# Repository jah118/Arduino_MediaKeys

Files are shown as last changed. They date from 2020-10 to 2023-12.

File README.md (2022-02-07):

# Arduino_MediaKeys

This project is to make custom key for windows, as of now it is used for media keys (prev,next,play/pause) and to use F19 and F16 to keybinds for discord or what key is defined

the future for project, is to add a display that can pull information from spotify and display the song and more info as a start.

# Dependencies:

HID-Project by NicoHood Version 2.5.0 or above

- can be found in Arduino Lirary Manager
- or: https://github.com/NicoHood/HID

BOUNCE 2 Debouncing library for Arduino and Wiring by Thomas Ouellet Fredericks
- can be found in Arduino Lirary Manager
- or:  https://github.com/thomasfredericks/Bounce2

# Reference:

The Reference links below is where the info to getting the project to work comes from

- https://uboopenfactory.univ-brest.fr/Les-Labs/MusicLab/Projets/Arduino-Media-Keys

## Most code inspiration comes from here:

- https://github.com/NicoHood/HID/wiki
- https://www.arduino.cc/reference/en/language/functions/usb/keyboard/
- https://www.stefanjones.ca/blog/arduino-leonardo-remote-multimedia-keys/
- https://arduino.stackexchange.com/questions/8934/send-keyboard-media-keys-with-keyboard-library
- http://www.freebsddiary.org/APC/usb_hid_usages.php
- list of hid codes for further use or differt use case
  https://www.instructables.com/id/USB-Volume-Control-and-Caps-Lock-LED-Simple-Cheap-/

# PCB

`the pcb was design in eagle`  
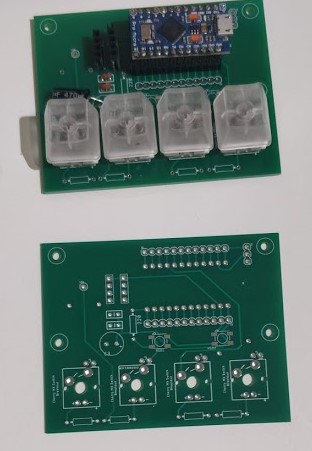
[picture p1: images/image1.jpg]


### With old prototype board

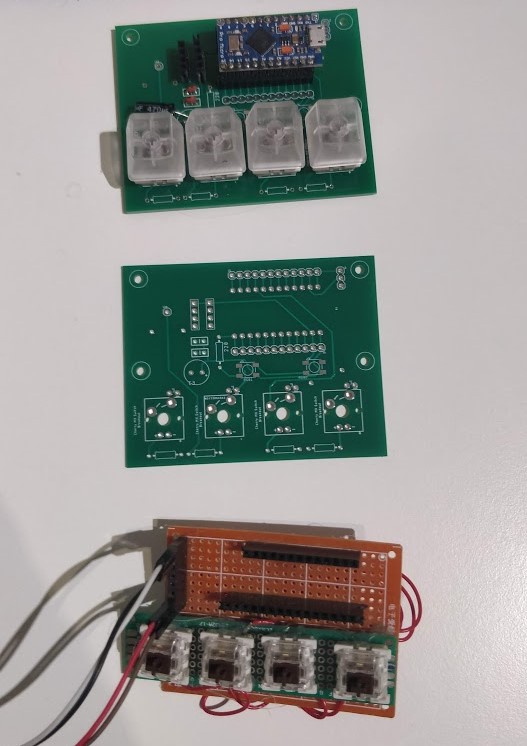
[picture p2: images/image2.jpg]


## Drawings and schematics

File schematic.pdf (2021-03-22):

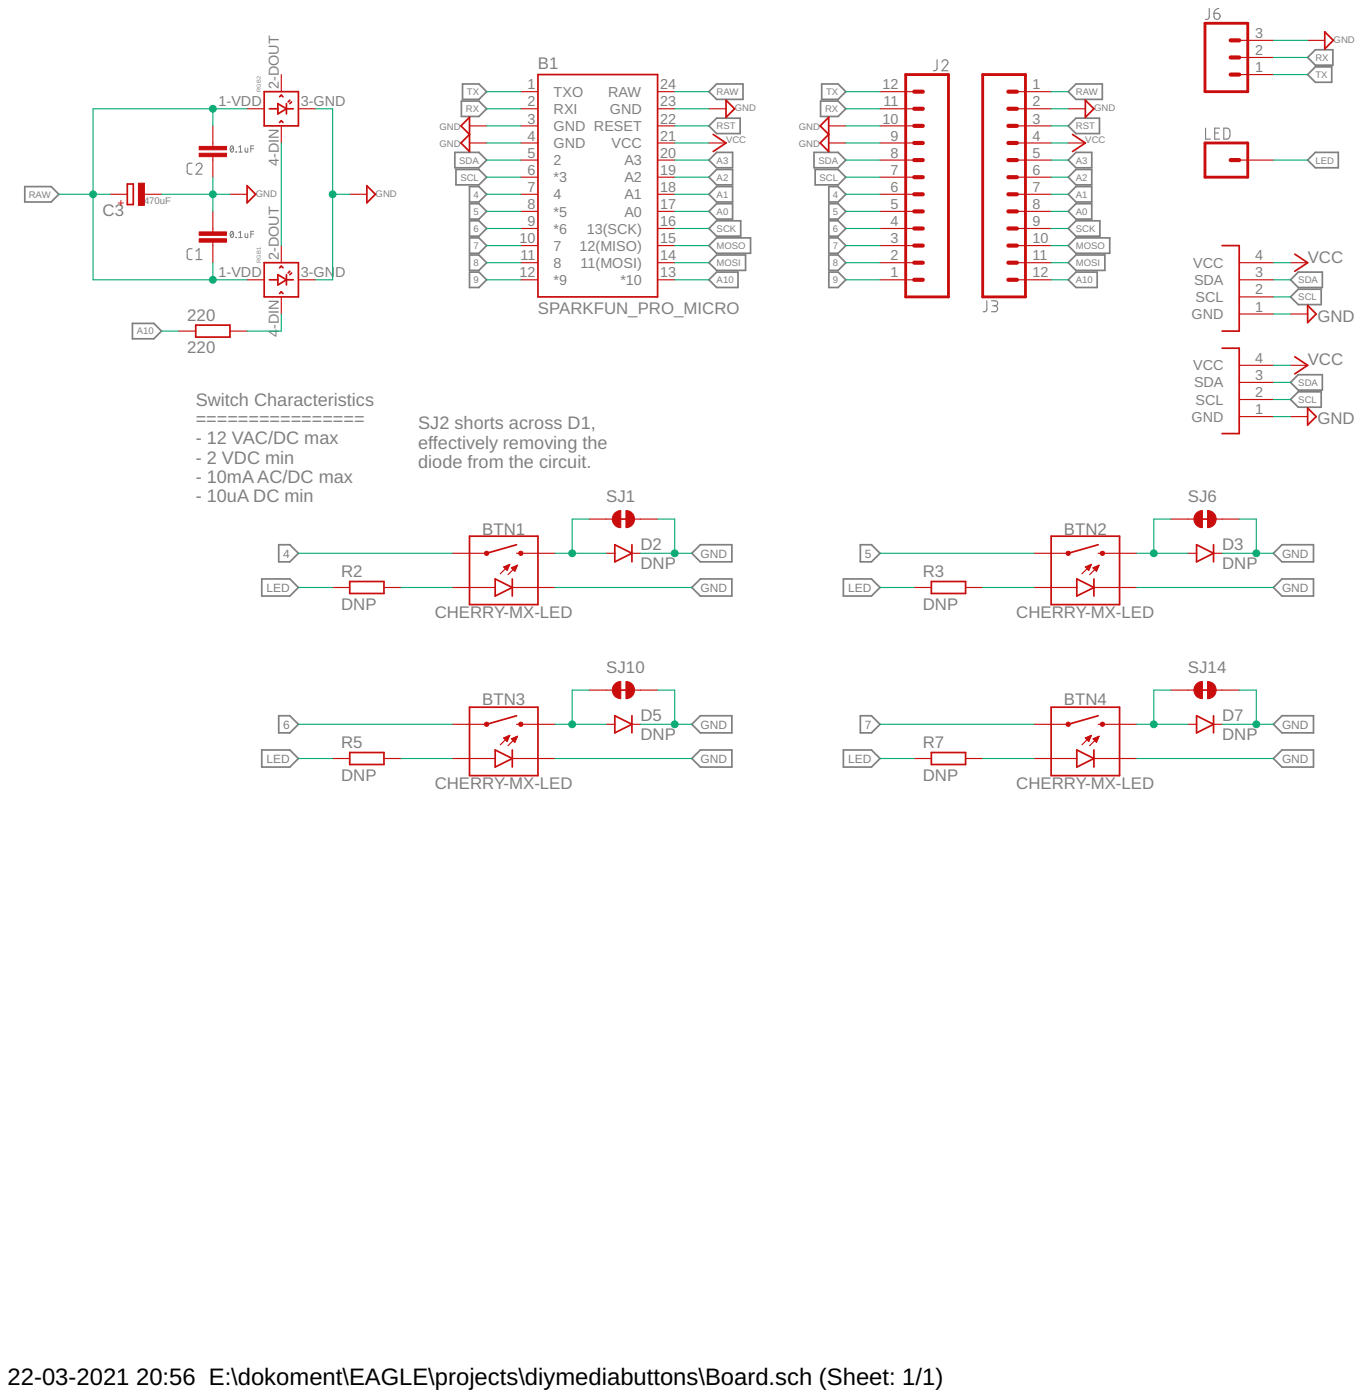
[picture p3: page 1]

diode from the circuit. Switch Characteristics ================

SJ2 shorts across D1, effectively removing the

22-03-2021 20:56 E:\dokoment\EAGLE\projects\diymediabuttons\Board.sch (Sheet: 1/1)

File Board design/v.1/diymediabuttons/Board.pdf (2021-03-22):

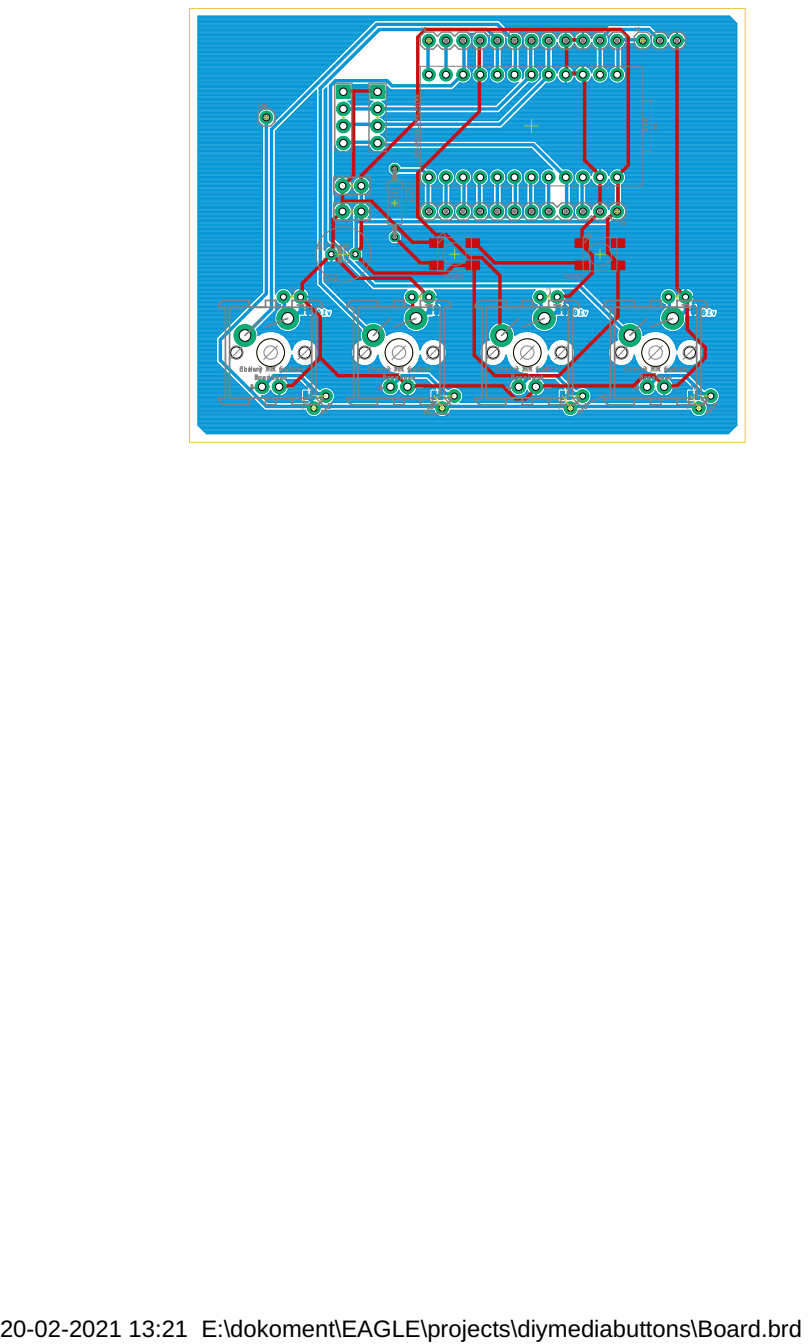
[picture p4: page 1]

20-02-2021 13:21 E:\dokoment\EAGLE\projects\diymediabuttons\Board.brd

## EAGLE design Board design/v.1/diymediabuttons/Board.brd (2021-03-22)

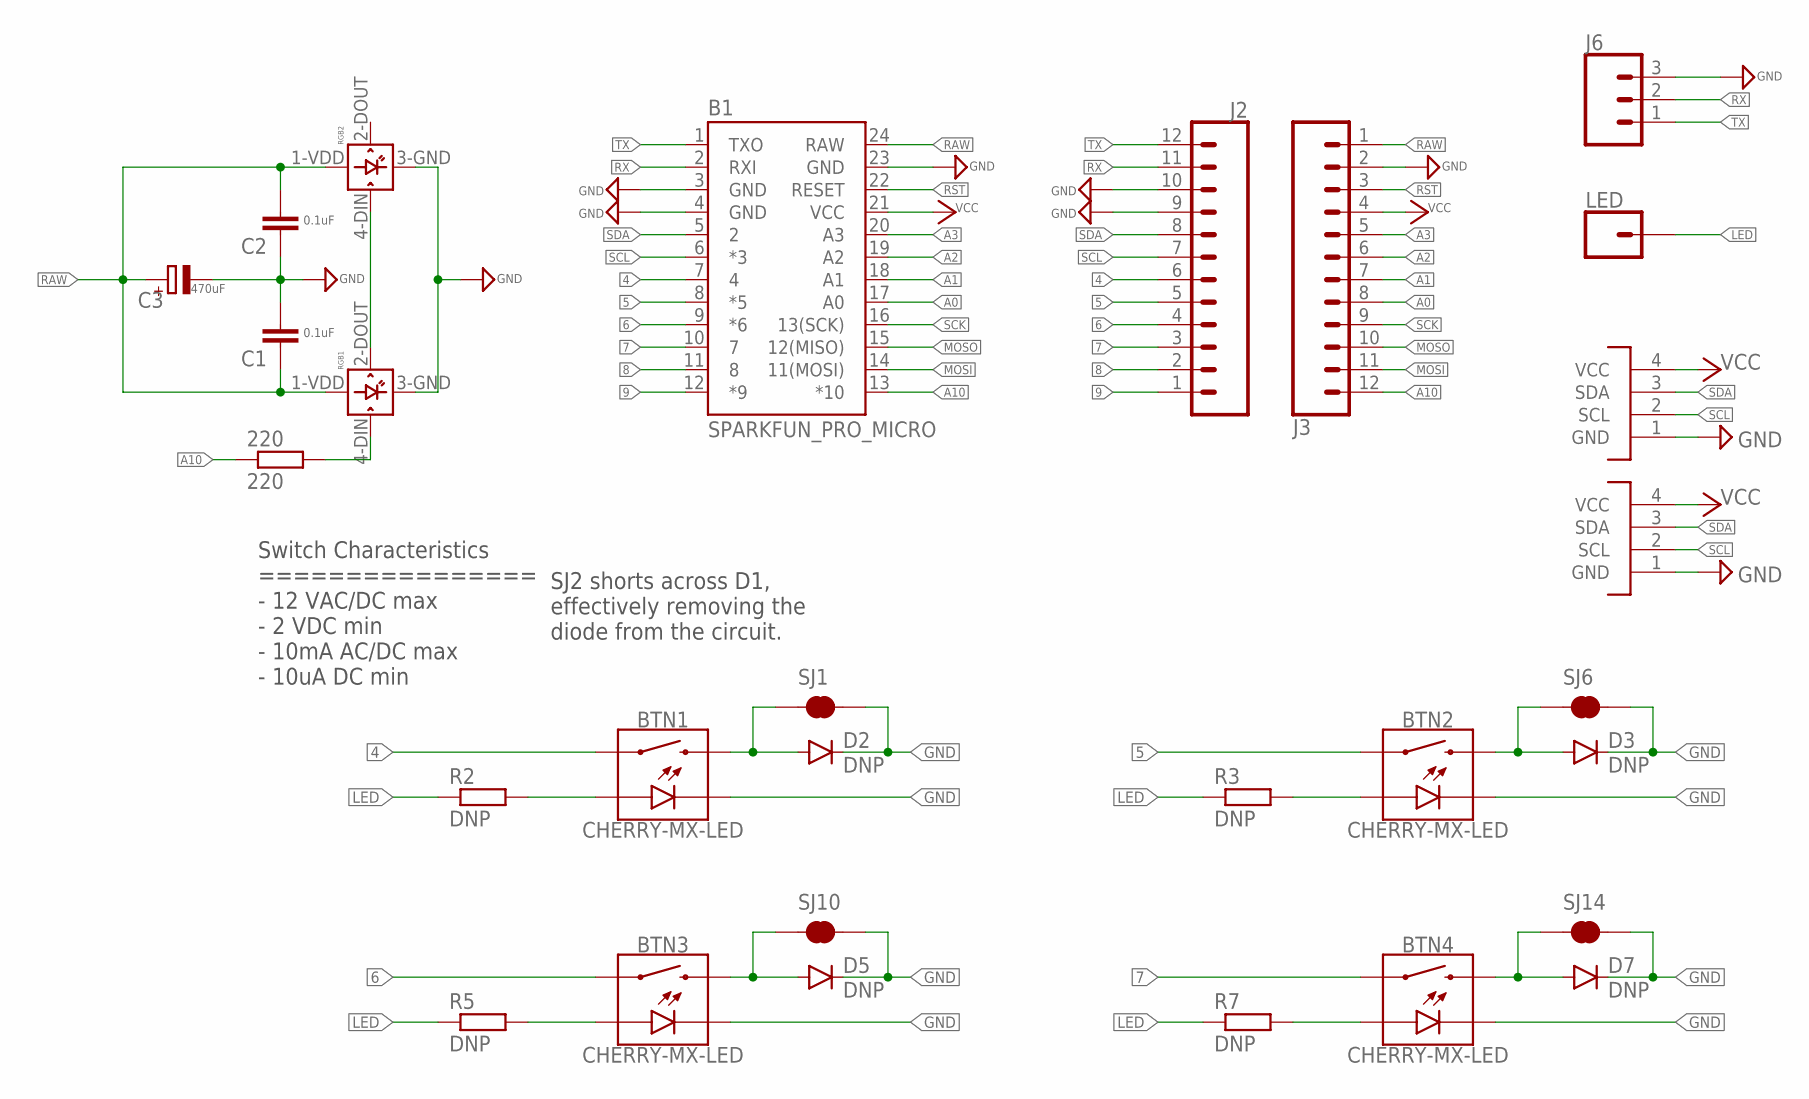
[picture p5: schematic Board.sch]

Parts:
220: 220; 0207/10
B1: SPARKFUN_PRO_MICRO
BTN1, BTN2, BTN3, BTN4: CHERRY-MX-LED
C1, C2: 0.1uF; CAP-PTH-SMALL-KIT
C3: 470uF; E3,5-8
D2, D3, D5, D7: DNP; DIODE-PTH-0.1
J2, J3: CONN_12; 1X12
J4, J5: I2C-HEADER; HEADER-4X1-2.54
J6: CONN_03; 1X03
LED: CONN_01; 1X01
R2, R3, R5, R7: DNP; 0207/10
RGB1, RGB2: WS2812B
SJ1, SJ6, SJ10, SJ14: JUMPER-PAD-2-NC_BY_TRACENO_SILK; PAD-JUMPER-2-NC_BY_TRACE_NO_SILK

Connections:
4: B1.7 (4), BTN1.S1, J2.6
5: B1.8 (*5), BTN2.S1, J2.5
6: B1.9 (*6), BTN3.S1, J2.4
7: B1.10 (7), BTN4.S1, J2.3
8: B1.11 (8), J2.2
9: B1.12 (*9), J2.1
A0: B1.17 (A0), J3.8
A1: B1.18 (A1), J3.7
A2: B1.19 (A2), J3.6
A3: B1.20 (A3), J3.5
A10: 220.1, B1.13 (*10), J3.12
GND: B1.3 (GND), B1.4 (GND), B1.23 (GND), BTN1.K (C), BTN2.K (C), BTN3.K (C), BTN4.K (C), C1.2, C2.1, C3.-, D2.C, D3.C, D5.C, D7.C, J2.9, J2.10, J3.2, J4.1 (GND), J5.1 (GND), J6.3, RGB1.3-GND (GND), RGB2.3-GND (GND), SJ1.2, SJ6.2, SJ10.2, SJ14.2
LED: LED.1, R2.1, R3.1, R5.1, R7.1
MOSI: B1.14 (11(MOSI)), J3.11
MOSO: B1.15 (12(MISO)), J3.10
unnamed: BTN1.A, R2.2
unnamed: 220.2, RGB1.4-DIN (DIN)
unnamed: RGB1.2-DOUT (DOUT), RGB2.4-DIN (DIN)
unnamed: BTN1.S2, D2.A, SJ1.1
unnamed: BTN2.A, R3.2
unnamed: BTN2.S2, D3.A, SJ6.1
unnamed: BTN3.A, R5.2
unnamed: BTN3.S2, D5.A, SJ10.1
unnamed: BTN4.A, R7.2
unnamed: BTN4.S2, D7.A, SJ14.1
RAW: B1.24 (RAW), C1.1, C2.2, C3.+, J3.1, RGB1.1-VDD (VDD), RGB2.1-VDD (VDD)
RST: B1.22 (RESET), J3.3
RX: B1.2 (RXI), J2.11, J6.2
SCK: B1.16 (13(SCK)), J3.9
SCL: B1.6 (*3), J2.7, J4.2 (SCL), J5.2 (SCL)
SDA: B1.5 (2), J2.8, J4.3 (SDA), J5.3 (SDA)
TX: B1.1 (TXO), J2.12, J6.1
VCC: B1.21 (VCC), J3.4, J4.4 (VCC), J5.4 (VCC)

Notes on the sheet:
SJ2 shorts across D1, effectively removing the diode from the circuit.
Switch Characteristics ================ - 12 VAC/DC max - 2 VDC min - 10mA AC/DC max - 10uA DC min

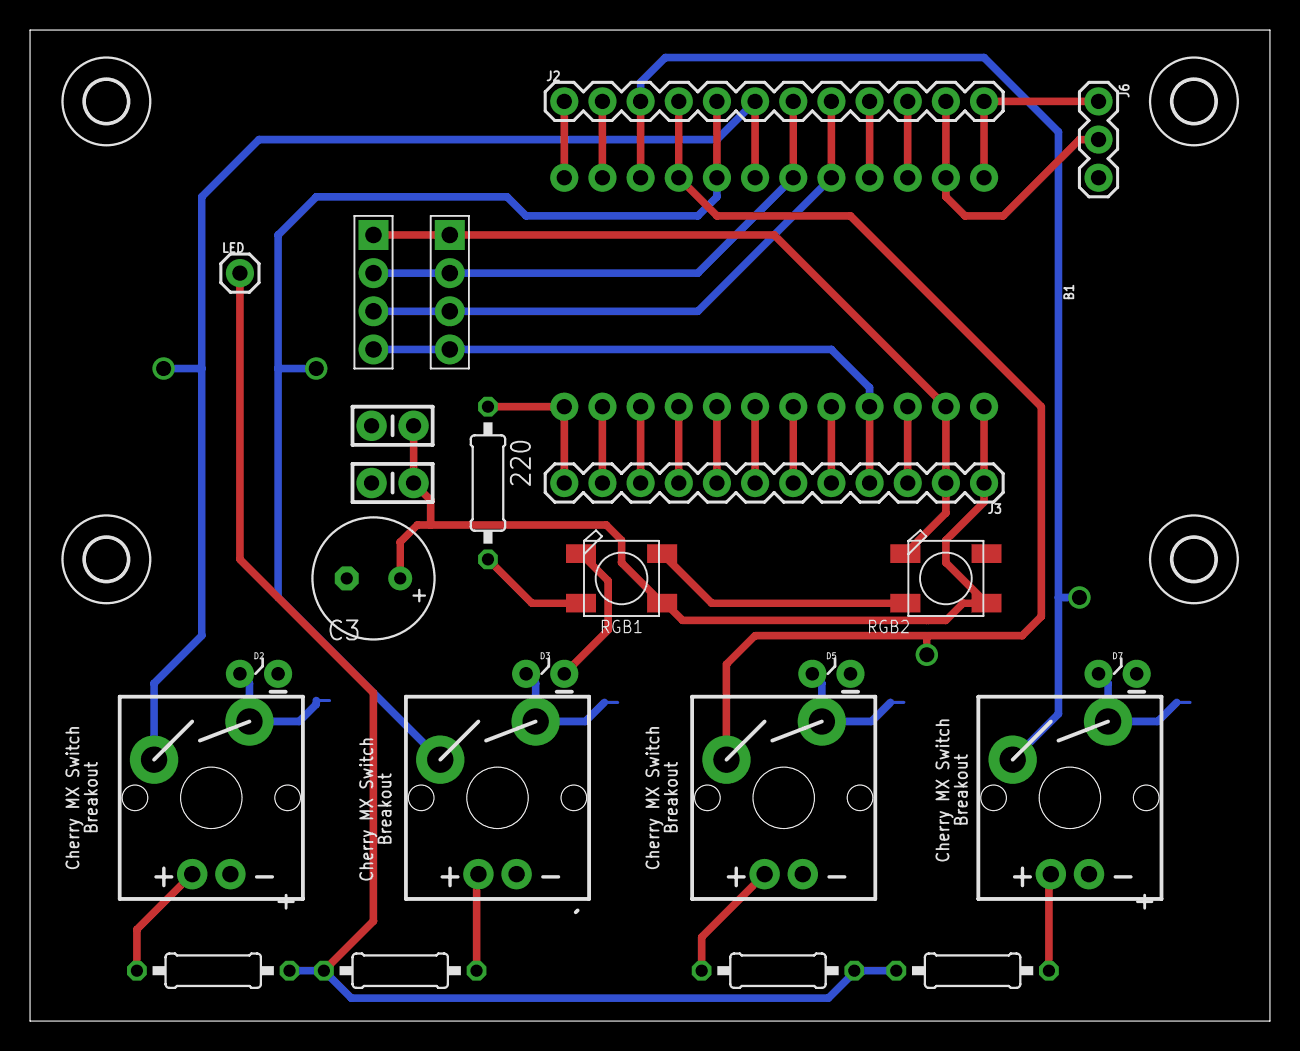
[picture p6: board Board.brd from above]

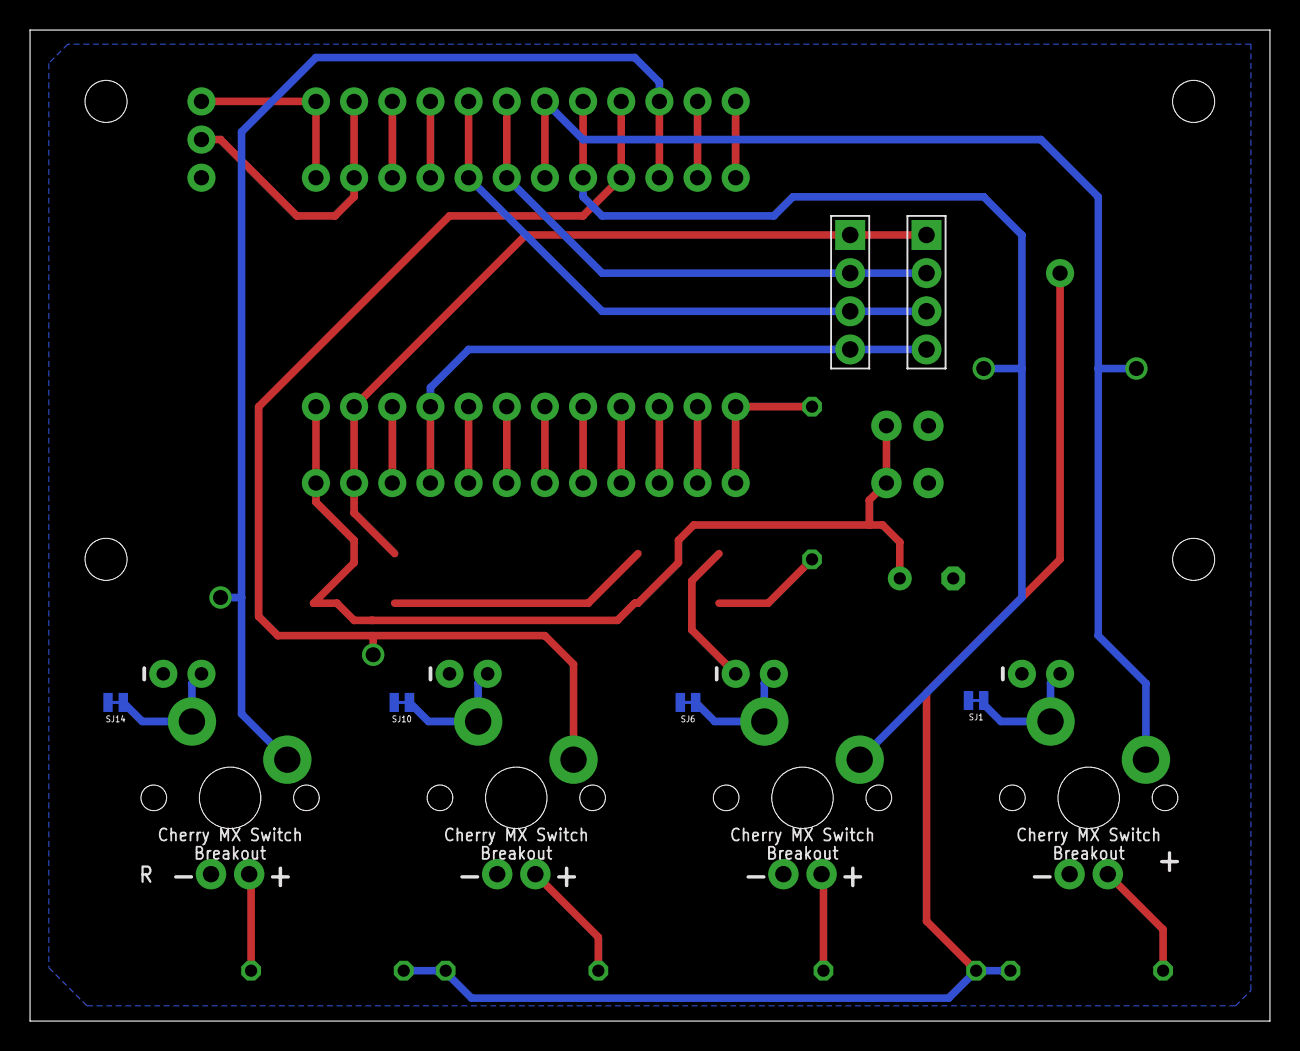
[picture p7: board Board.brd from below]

Board: 2 copper layers, 82.5 x 66.0 mm, 33 parts (4 on the bottom side), 33 nets.

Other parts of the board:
U$1, U$2, U$3, U$4: 2,8

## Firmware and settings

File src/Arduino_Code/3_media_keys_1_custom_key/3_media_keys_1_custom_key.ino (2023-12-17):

/*
  Jonas

  Arduino Media Keys
  Version V0.8.1
  10/12/2023

  Dependencies:
  - HID-Project by NicoHood Version 2.8.4 or above
    -- can be found in Arduino Lirary Manager
    -- or: https://github.com/NicoHood/HID
  
  - FastLED
  - Bounce2

  Reference:
  The Reference links below is where the info to getting the project to work comes from
   @see https://uboopenfactory.univ-brest.fr/Les-Labs/MusicLab/Projets/Arduino-Media-Keys
  - most code comes from here.
  @see https://github.com/NicoHood/HID/wiki
  @see https://www.arduino.cc/reference/en/language/functions/usb/keyboard/
  @see https://www.stefanjones.ca/blog/arduino-leonardo-remote-multimedia-keys/
  @see https://arduino.stackexchange.com/questions/8934/send-keyboard-media-keys-with-keyboard-library
  @see http://www.freebsddiary.org/APC/usb_hid_usages.php
  - list of hid codes for further use or differt use case
  @see https://www.instructables.com/id/USB-Volume-Control-and-Caps-Lock-LED-Simple-Cheap-/
  @see https://docs.arduino.cc/hacking/software/LibraryTutorial

  double press solutin based on:
  MULTI-CLICK:  One Button, Multiple Events Based on "https://jmsarduino.blogspot.com/2009/10/4-way-button-click-double-click-hold.html"

*/


/*
  ///       V0.8 - done
      use #include <Bounce2.h> for better double  press
      https://arduino.stackexchange.com/questions/69897/detecting-how-many-button-pressessingle-tap-double-tap-etc-with-two-simultane

      ensure / add support for auto change beween linux and windows.
  
  ///       V0.8.1 - done
      * Replaced Bounce2.h as  double  press handler using :
        MULTI-CLICK:  One Button, Multiple Events Based on "https://jmsarduino.blogspot.com/2009/10/4-way-button-click-double-click-hold.html"

      *  Moved  Button code to lib : Button.h
      * started on V0.9.0 base classes for loading confs

  ///       TODO FOR V0.9.0
      change over to load key map file - maybejson
      read json AND  read it from pc program or some nice wayy that needs no reflash :
      https://forum.arduino.cc/t/writing-to-flash-from-application-please-test-and-enjoy/320295
      https://arduinoplusplus.wordpress.com/2019/04/02/persisting-application-parameters-in-eeprom/
      https://arduinojson.org/v6/how-to/store-a-json-document-in-eeprom/
      https://arduinojson.org/
      https://arduinojson.org/v6/how-to/reduce-memory-usage/

  ///        TODO goals for v1.0.0
        add serial support between arduione and esp to send keypress or recives keypress
      - reason this is to add support for esp or raspberry zero with screen that shows media status.
      - if zero is used then a webpage can be used. show and pull data from there. do browser in terminal to save resources, and make it host is own webpages that is displayed
      - if esp is used thne look in to building ui that where some part is static and and only progress bar moves https://forum.arduino.cc/t/tft-touch-reaching-high-refresh-rate-cost-effectively/595823/6
        and rest of sreen updates only on new song changed (this not for first version, first version shows the name of the song played  )
        https://www.youtube.com/watch?v=rq5yPJbX_uk
        https://www.esp8266.com/viewtopic.php?f=32&t=16366


*/


/// look up hid projekt to see Languages  or see AlternateLanguageLayout.ino from hid project for example
#define HID_CUSTOM_LAYOUT  // set this flag to indicate that a custom layout is selected
#define LAYOUT_DANISH      // set this flag after the above flag to indicate the custom input method is DANISH

/// include the HID library
#include "HID-Project.h"
#include "FastLED.h"
#include "Bounce2.h"

/// @todo add defin things to struct and load from json



//------------------------------ rgb ------------------------------
#define DATA_PIN 9
//#define CLK_PIN 4
#define LED_TYPE WS2811
#define COLOR_ORDER GRB
#define NUM_LEDS 8
#define BRIGHTNESS 32

/// @todo maybe move beacause of loading order of data and info from config
CRGB leds[NUM_LEDS];

int rgbState = 1;
int lastrgbState = 0;

/// ------------------------------ Buttons press vars ------------------------------
/// press var's for determening a press or double press
const int holdTime = 1000;
const unsigned long lastSwitchTime = 0;
const long DCgap = 250;   // 150 //230   // time for captureing a double press
const int debounce = 20;  // 50 //20 // 35
const byte BUTTON_DEBOUNCE_INTERVAL = 25;

const byte buttonPin1 = 4;  // key 1 backButton
const byte buttonPin2 = 5;  // key 2 playButton
const byte buttonPin3 = 6;  // key 3 fwdButton
const byte buttonPin4 = 7;  // key 4 customButton F16/F19

const uint8_t buttonPin1Action = MEDIA_PREVIOUS;
const uint8_t buttonPin2Action = MEDIA_PLAY_PAUSE;
const uint8_t buttonPin3Action = MEDIA_NEXT;
const uint8_t buttonPin4Action1 = KEY_F19;
const uint8_t buttonPin4Action2 = KEY_F16;

/// ------------------------------ DEBUG ------------------------------
/// Determs if Serial.print is enabled
const bool debugState = false;

void isDebugTruePrintToSerial(String temp) {
  if (debugState) {
    Serial.println(temp);
  }
}

/// ------------------------------ Dataconf ------------------------------
/// Struct to hold the general config like colours.
struct Config {
  char layout;
  uint16_t datapin;
  char ledtype;
  char colororder;
  uint16_t nleds;
  uint16_t brightness;
  uint8_t debounce;  // ms debounce period to prevent flickering when pressing or releasing the button
  uint8_t holdTime;  // ms hold period: how long to wait for press+hold event
  uint8_t DCgap;     // max ms between clicks for a double click event
  uint8_t attempts;
  uint16_t attemptdelay;
};

///--------- Internal references ------------
/// (this needs to be below all structs etc..) this may needed to be loaded after struct
/// #include "configLoad.h"
#include "Button.h"

/// -------------- Start Button  ----------------------
/// Bounce2.h lib setup
Bounce button1Debouncer = Bounce();
Bounce button2Debouncer = Bounce();
Bounce button3Debouncer = Bounce();

/// Button.h lib setup
Button Button1(buttonPin1, debugState);
Button Button2(buttonPin2, debugState);
Button Button3(buttonPin3, debugState);
Button Button4(buttonPin4, debugState);

// -------------- Start filesystem ----------------------

// if (!FILESYSTEM.begin())
//{
//   Serial.println("[ERROR]: SPIFFS initialisation failed!");
//   drawErrorMessage("Failed to init SPIFFS! Did you upload the data folder?");
//   while (1)
//     yield(); // We stop here
// }
// Serial.println("[INFO]: SPIFFS initialised.");
//
//// Check for free space
//
// Serial.print("[INFO]: Free Space: ");
// Serial.println(SPIFFS.totalBytes() - SPIFFS.usedBytes());

//------------------ Load Config ----------------------------------------------

// Serial.println("[INFO]: Loading Config");
// if (!configLoad())
//{
//   Serial.println("[WARNING]: Failed to load config!");
// }
// else
//{
//   Serial.println("[INFO]: Config Loaded");
// }

//------------------ Functions ----------------------------------------------


/// @todo
/// n = how many leds need be turned on, is used as a array this enables to not turn all the leds.
/// state = used for turning the leds on and of as a toggle
void turnOnRGBByState(int cRed, int cGreen, int cBlue, bool state, int ledIndex) {
  if (ledIndex < 0 || ledIndex >= NUM_LEDS) {
    isDebugTruePrintToSerial("ledIndex out of range");
    return;  // Handle out-of-range index
  }

  switch (state) {
    case 0:  // Turn on LEDs with the specified color
      FastLED.clear();
      for (int i = 0; i < NUM_LEDS; i++) {
        leds[ledIndex + i] = CRGB(cRed, cGreen, cBlue);
      }
      FastLED.show();

      /// Update state variables
      lastrgbState = 0;
      rgbState = 0;
      break;

    case 1:  // Turn off LEDs
      FastLED.clear();
      FastLED.show();

      /// Update state variables
      lastrgbState = 0;
      rgbState = 0;
      break;
  }
}

/// Handles the button press events from Button::CheckButtonEvent() where:
/// Click = 1, Double-Click = 2, Hold = 3, Long Hold = 4
/// takes two KeyboardKeycode as argument from HID-Project.h for single press and double press for the button that is pressed
void pressEventHandler(int event, KeyboardKeycode key, KeyboardKeycode key2) {
  switch (event) {
    case 1:
      clickEvent();
      isDebugTruePrintToSerial("single press");
      Keyboard.write(key);
      switch (rgbState) {
        case 0:
          isDebugTruePrintToSerial("case 0");
          turnOnRGBByState(0, 0, 0, lastrgbState, 0);
          rgbState = 1;
          break;
        case 1:
          isDebugTruePrintToSerial("case 1");
          turnOnRGBByState(255, 0, 0, lastrgbState, 0);
          rgbState = 0;
          break;
      }
      break;
    case 2:
      doublePress(key2);
      doubleClickEvent();
      break;
    case 3:
      holdEvent();
      break;
    case 4:
      longHoldEvent();
      break;
    default:
      break;
  }
}

/// Double press handler, called from pressEventHandler() can be used for other things, takes a KeyboardKeycode as argument from HID-Project.h
void doublePress(KeyboardKeycode key) {
  isDebugTruePrintToSerial("double press");
  Keyboard.write(key);  // Action to be performed on double press
  turnOnRGBByState(0, 0, 250, lastrgbState, 0);
}

/// Initializes buttons and debouncers for setup.
void setupButtons() {
  /// Define the pin mode for each pin used
  pinMode(buttonPin1, INPUT_PULLUP);
  pinMode(buttonPin2, INPUT_PULLUP);
  pinMode(buttonPin3, INPUT_PULLUP);
  pinMode(buttonPin4, INPUT_PULLUP);

  ///& BUTTON Setup for Bounce2
  button1Debouncer.attach(buttonPin1);
  button2Debouncer.attach(buttonPin2);
  button3Debouncer.attach(buttonPin3);

  /// DEBOUNCE INTERVAL IN MILLISECONDS
  button1Debouncer.interval(BUTTON_DEBOUNCE_INTERVAL);
  button2Debouncer.interval(BUTTON_DEBOUNCE_INTERVAL);
  button3Debouncer.interval(BUTTON_DEBOUNCE_INTERVAL);
}

void setup() {
  Serial.begin(115200);
  /// Delay for recovery
  delay(20);

  /// Encapsulated buttons and debouncers basic setup
  setupButtons();

  /// Begin HID connection
  Keyboard.begin();
  Consumer.begin();

  /// 1.5 second delay for recovery and HID connection is sometime unstable at start, this limits it to less. But may not be needed.
  delay(1500);

  /// Tell FastLED about the LED strip configuration
  FastLED.addLeds<LED_TYPE, DATA_PIN, COLOR_ORDER>(leds, NUM_LEDS)
    .setCorrection(TypicalLEDStrip)
    .setDither(BRIGHTNESS < 255);


  FastLED.setBrightness(BRIGHTNESS);  // set master brightness control
  for (int dot = 0; dot < NUM_LEDS - 1; dot++) {
    FastLED.show();
    leds[dot] = CRGB::Black;  // clear this led for the next time around the loop
    delay(30);
  }
}

void loop() {
  /// Calls the Update function as fast as possible.
  Button1.Update();
  Button2.Update();
  Button3.Update();
  Button4.Update();

  /// Button 1 pressed.
  if (button1Debouncer.update()) {
    if (button1Debouncer.fell())  // key is pressed down
    {
      Consumer.write(buttonPin1Action);  // send HID command
      isDebugTruePrintToSerial("Back");
      
      /// Check if button 1 and 2 pressed together
      if (digitalRead(buttonPin2) == 0) {
        Button1.IncrementCounter();
      }
    }
  }

  /// Button 2 pressed.
  if (button2Debouncer.update()) {
    if (button2Debouncer.fell())  // key is pressed down
    {
      Consumer.write(buttonPin2Action);  // send HID command
      isDebugTruePrintToSerial("Play/Pause");
      /// Check if button 1 and 2 pressed together
      if (digitalRead(buttonPin1) == 0) {
        Button1.IncrementCounter(Button2);
      }
    }
  }

  /// Button 3 pressed.
  if (button3Debouncer.update()) {
    if (button3Debouncer.fell())  // key is pressed down
    {
      /// Check if button 3 and 4 pressed together
      if (digitalRead(buttonPin4) == 0) {
        Button3.IncrementCounter();
      } else {
        Consumer.write(buttonPin3Action);  // send HID command
        isDebugTruePrintToSerial("Next");
      }
    }
  }

  int b = Button4.CheckButtonEvent();
  pressEventHandler(b, buttonPin4Action1, buttonPin4Action2);  // this is only for button 4
}

/// @todo this part of prep for v0.9.0
/// Events to trigger -- TODO this has to be generict so configlod fits into these events where a button returns event int and then conf can be read an executed

void clickEvent() {
  isDebugTruePrintToSerial("clickEvent");
}
void doubleClickEvent() {
  isDebugTruePrintToSerial("doubleClickEvent");
}
void holdEvent() {
  isDebugTruePrintToSerial("holdEvent");
}
void longHoldEvent() {
  isDebugTruePrintToSerial("longHoldEvent");
}

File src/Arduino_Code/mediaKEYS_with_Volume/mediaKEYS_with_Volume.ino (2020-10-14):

/*
  Jonas

  Arduino Media Keys
  Version 0.5
  9/08/2020

  Dependencies:
  HID-Project by NicoHood Version 2.5.0 or above
  - can be found in Arduino Lirary Manager
  - or: https://github.com/NicoHood/HID

  Reference:
  The Reference links below is where the info to getting the project to work comes from
  https://uboopenfactory.univ-brest.fr/Les-Labs/MusicLab/Projets/Arduino-Media-Keys
  - most code comes from here.
  https://github.com/NicoHood/HID/wiki
  https://www.stefanjones.ca/blog/arduino-leonardo-remote-multimedia-keys/
  https://arduino.stackexchange.com/questions/8934/send-keyboard-media-keys-with-keyboard-library
  http://www.freebsddiary.org/APC/usb_hid_usages.php
  - list of hid codes for further use or differt use case
  https://www.instructables.com/id/USB-Volume-Control-and-Caps-Lock-LED-Simple-Cheap-/
*/


// include the HID library
#include "HID-Project.h"
#include "FastLED.h" // 

//rgb

#define DATA_PIN 9
//#define CLK_PIN 4
#define LED_TYPE WS2811
#define COLOR_ORDER GRB
#define NUM_LEDS 4
#define BRIGHTNESS 32

CRGB leds[NUM_LEDS];

int rgbState = 1;
int lastrgbState = 0;


//test singel or double press of keyy

unsigned long onTime;
int lastReading = LOW;
int bounceTime = 35; //50
int holdTime = 500; //500
unsigned int hold = 0;

long lastSwitchTime = 0;
long doubleTime = 230; // 150

const int f20Button = 8;
const int f16Button = 7;
int reading;

// definitions for each pin used
//const int pinLed = LED_BUILTIN;


const int volUpButton = 2;
const int volDwnButton = 3;
const int muteButton = 4;
const int playButton = 5;
const int fwdButton = 7;
const int backButton = 6;

const int delayConst75 = 75;
const int delayConst250 = 250;

const bool debugState = true;

void isDebugTruePrintToSerial(String temp) {
  if (debugState) {
    Serial.println(temp);
  }
}

void turnOnRGBByState (int cRed, int cGreen, int cBlue, bool state, int n) {

  switch (state) {
    case 0:
      FastLED.clear();
      leds[n] = CRGB( cRed, cGreen, cBlue);
      isDebugTruePrintToSerial(state + "");
      isDebugTruePrintToSerial(lastrgbState + "");
      FastLED.show();
      lastrgbState = 0;
      rgbState = 0;
      break;
    case 1:
      isDebugTruePrintToSerial("reddd");
      FastLED.clear();
      isDebugTruePrintToSerial("lastrgbState black");
      isDebugTruePrintToSerial(lastrgbState + "");
      leds[2] = CRGB::Black;
      FastLED.show();
      lastrgbState = 0;
      rgbState = 0;
      break;
  }

}

void press () {
  if ((millis() - lastSwitchTime) < doubleTime) {
    isDebugTruePrintToSerial("double press");

    BootKeyboard.write(KEY_F16);
    turnOnRGBByState (0, 0, 250, lastrgbState, 2);

    //    switch (lastrgbState) {
    //      case 0:
    //        FastLED.clear();
    //        leds[2] = CRGB::Blue; 66
    //        isDebugTruePrintToSerial("blues");
    //        isDebugTruePrintToSerial("lastrgbState");
    //        isDebugTruePrintToSerial(lastrgbState + "");
    //        FastLED.show();
    //        lastrgbState = 0;
    //        rgbState = 0;
    //        break;
    //      case 1:
    //        isDebugTruePrintToSerial("reddd");
    //        FastLED.clear();
    //        isDebugTruePrintToSerial("lastrgbState black");
    //        isDebugTruePrintToSerial(lastrgbState + "");
    //        leds[2] = CRGB::Black;
    //        FastLED.show();
    //        lastrgbState = 0;
    //        rgbState = 0;
    //        break;
    //    }
  }  else if ((millis() - lastSwitchTime) > doubleTime) {
    isDebugTruePrintToSerial("single press");
    BootKeyboard.write(KEY_F19);
    switch (rgbState) {
      case 0:
        isDebugTruePrintToSerial("case 0");
        isDebugTruePrintToSerial("lastrgbState");
        isDebugTruePrintToSerial(lastrgbState + "");

        isDebugTruePrintToSerial("rgbState black");
        isDebugTruePrintToSerial(rgbState + "");
        FastLED.clear();
        leds[0] = CRGB::Black;
        FastLED.show();
        rgbState = 1;
        break;
      case 1:
        Serial.println("case 1");

        if (lastrgbState == 1) {
          delay(30);
          isDebugTruePrintToSerial("case  1");
          isDebugTruePrintToSerial("lastrgbState");
          isDebugTruePrintToSerial(lastrgbState + "");

          isDebugTruePrintToSerial("rgbState black");
          isDebugTruePrintToSerial(rgbState + "");
          FastLED.clear();
          leds[1] = CRGB::Black;
          FastLED.show();
          lastrgbState = 0;
          rgbState = 0;
        } else {
          isDebugTruePrintToSerial("lastrgbState ffffff");
          isDebugTruePrintToSerial(lastrgbState + "");

          isDebugTruePrintToSerial("rgbState red");
          isDebugTruePrintToSerial(rgbState + "");

          leds[0] = CRGB::Red;
          FastLED.show();
          rgbState = 0;
          isDebugTruePrintToSerial(" new val rgbState red");
          isDebugTruePrintToSerial(rgbState + "");
        }

        break;
    }
  }
  lastSwitchTime = millis();
}


void setup() {
  Serial.begin(115200);
  delay(1000);
  // define the pin mode for each pin used
  //  pinMode(pinLed, OUTPUT);
  //  digitalWrite(pinLed, LOW);

  pinMode(playButton, INPUT_PULLUP);
  pinMode(fwdButton, INPUT_PULLUP);
  pinMode(backButton, INPUT_PULLUP);
  pinMode(volUpButton, INPUT_PULLUP);
  pinMode(volDwnButton, INPUT_PULLUP);
  pinMode(muteButton, INPUT_PULLUP);

  //press decllare
  pinMode(f20Button, INPUT_PULLUP );

  // begin HID connection
  BootKeyboard.begin();
  Consumer.begin();

  delay(3000); // 3 second delay for recovery
  // tell FastLED about the LED strip configuration
  FastLED.addLeds<LED_TYPE, DATA_PIN, COLOR_ORDER>(leds, NUM_LEDS)
  .setCorrection(TypicalLEDStrip)
  .setDither(BRIGHTNESS < 255);

  // set master brightness control
  FastLED.setBrightness(BRIGHTNESS);

  for (int dot = 0; dot < NUM_LEDS; dot++) {

    FastLED.show();
    // clear this led for the next time around the loop
    leds[dot] = CRGB::Black;
    delay(30);
  }

  reading = digitalRead(f20Button);
}
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

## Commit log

2020-10-14 switch to turnOnRGBByState funktion
    turnOnRGBByState is used now instead of having dulicet code and removede dead code where state is check for within a state for single press and removed debug prints
2021-03-22 added pcb board
    [Board.brd, Board.sch, DRILEGEND.CFG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]
2022-02-22 exsample for how button data could be saved
2022-02-27 Button lib works. config lib started
    the commit fokus on getting button func done and some trail and error about loading things to eeprom
    [3_media_keys_1_custom_key.ino, Button.cpp]
2023-12-17 Refactor: Changed comment style
    - Updated: pressEventHandler to take KeyboardKeycode to make use of buttonPin4Action1 and buttonPin4Action2
    - The code now uses /// instead of //, for general comments

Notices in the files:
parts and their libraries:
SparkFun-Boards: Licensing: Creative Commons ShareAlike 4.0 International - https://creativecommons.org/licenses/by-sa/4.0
